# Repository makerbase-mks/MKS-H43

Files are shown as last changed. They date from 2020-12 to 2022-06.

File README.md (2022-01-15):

# MKS-H43
MKS H43 is a 4.3-inch high-definition IPS display with a resolution of 800*480 and uses a capacitive touch screen. It is a high-end screen, which be adapted to most FDM 3D printer motherboards on the market， very suitable for 3D printer upgrades.
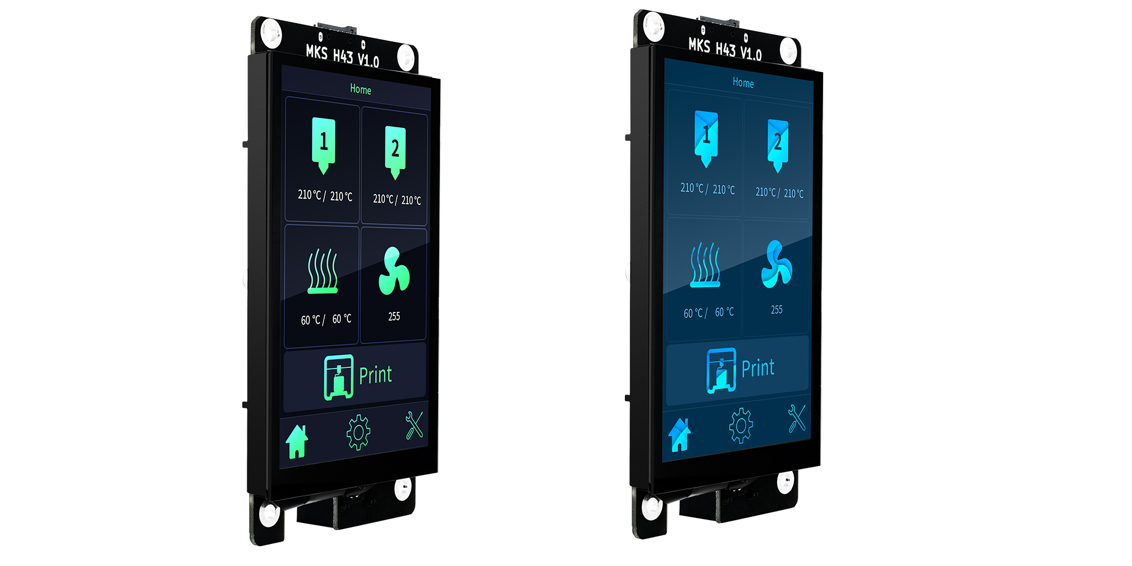
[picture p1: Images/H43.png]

# Feathers
```
—————————————————————————————————————————————————————————————————————————
   Display Size                  4.3 inches
_________________________________________________________________________
   Resolution                    800*480
_________________________________________________________________________
   LCD material                  IPS
_________________________________________________________________________
   Touch screen                  Capacitive touch screen
_________________________________________________________________________
   Interface with motherboard    RJ11/AUX-1(Uart TTL)
_________________________________________________________________________
                                 MKS SGEN_L
                                 MKS Robin Nano Series          
                                 MKS Robin E3/E3D/E3P
                                 Creality3D V1.1.4(Ender3/Ender5 raw board)
    Motherboards support         BTT SKR Series
                                 ...
                                 (Theoretically support all motherboards with
                                 serial communication and running marlin V2.X firmware)
__________________________________________________________________________
   Communicate Protocol          DWIN DGUS
__________________________________________________________________________
```

# Motherboards support
MKS H43 is a serial LCD, it uses the TTL-UART to communicate with motherboards. So in theory, MKS H43 supports all motherboards with serial communication and running marlin V2.X firmware. As there are so many types of 3d printer motherboards, different motherboard has different uart available and unavailabe, so we make some test of the compatibility of MKS H43 and some motherboards, please refer to the [wiki page](https://github.com/makerbase-mks/MKS-H43/wiki).

# How to use
## Hardware connect
As we mentioned above, MKS H43 just uses TTL-UART to connect to the motherboard, in fact the 4 pin signals are:
```
DC5V
GND
UART-TX
UART-RX
```
And we designed two types of uart sockets on MKS H43: one AUX and one RJ11. We also made two type of adapter boards for connecting different motherboards: 
```
MKS H43 Apdator-A: Convert from RJ11/AUX to EXP1/EXP2 interface of most motherboards, it also extends a SD socket
MKS H43 Apdator-B: Convert from RJ11 to AUX-1 interface of most motherboards, and EXP1 of Creality3D V1.1.4 
```
The reason we added RJ11 socket is to allow users to use a spring wire (the microphone cable of an old telephone) to connect to the screen, so that the screen can be easily manipulated and placed.

What have to be aware of is: As the MKS H43 communicates with the motherboard using DWIN DGUS protocol, which is different from the simple gcode commands, so the motherboard should use a serial port different from the PC connection to connect to MKS H43, unless you don’t need PC control. So maybe your motherboard has the "AUX-1" socket, but if it shares the same serial port with the PC connection, you cannot connect at the same time.

There are many situations for different motherboards:
- With independent serial on AUX-1 interface, such as MKS SGEN_L V1/V2, you can use Adaptor-B adapter board
- With independent serial on EXP1/EXP2 interface, such as MKS GEN_L, which can use the Adaptor-A adapter board
- Without independent serial ports on AUX-1 or EXP1/EXP2, but there are independent serial ports with other forms of interfaces. You can use the Adaptor-B adapter board and use the corresponding cable to switch, such as Creality3D V1.1.4 / MKS Robin Nano V1/V2/V3 / BTT SKR V1.3/V1.4
- Only with the shared serial with PC connection, you can only use MKS H43 without PC connection.
- No serial interface(very rare), cannot use MKS H43

And for different motherboards, you can refer to the detail connection and configuration on [WIKI](https://github.com/makerbase-mks/MKS-H43/wiki).

The hardware information of MKS H43 and adaptor boards, you can refer to : https://github.com/makerbase-mks/MKS-H43/tree/main/hardware.

## Motherboard firmware
We have added the support to Marlin V2 firmware and uploaded the source code here: https://github.com/makerbase-mks/Marlin-V2.X-MKS-H43. At the time of writing this article, Marlin officially has not merged the support of MKS H43, after Marlin merge, you can directly use the official one.
### For Creality Ender3
There is a compiled-Marlin version for Creality Ender3 raw board Creality V1.1.4 on https://github.com/makerbase-mks/MKS-H43/tree/main/Marlin_firmware_released. It was compiled from the source code: https://github.com/makerbase-mks/Marlin-V2.X-MKS-H43, and had added the support of MKS H43.
### Marlin Config
1. Download the source frome: https://github.com/makerbase-mks/Marlin-V2.X-MKS-H43.
2. Using VSCode to open Marlin source, and modify the motherboard type on the "platformio.ini" according to yours, just like:
```
default_envs = mks_robin_nano35
```
3. Config the MKS DWIN
- Open the "Configuration.h" file, find "DGUS_LCD_UI_MKS" and enable it,
- Open the "Configuration_adv.h" file, find "LCD_SERIAL_PORT", and configure the serial port number used to connect to H43. Please make sure that "LCD_SERIAL_PORT" should be different with the "SERIAL_PORT" in "Configuration.h", as "SERIAL_PORT" is used to communicate with the PC. And the baudrate should be set to 115200 by default.

After config other options according to your machine, compile the source code, and update your motherboard. Then you can use the MKS H43 to display and touch!

## Update the firmware of MKS H43
The firmware of MKS H43 has been burned before leaving the factory, so it is generally not necessary to update the firmware. But if you need to update the firmware version, or you want to customize the display interface, you can update according to the following method:
1. Prepare a TF card, format the TF card into FAT32 format, with 4096 bytes aligned.
2. The firmware of MKS H43 can be found on https://github.com/makerbase-mks/MKS-H43/tree/main/DWIN_SET_For_H43, download the version you need. Copy "DWIN_SET" folder to TF card after decompression.
3. Power off the MKS H43, insert the TF card into MKS H43, then power on. An automatic update interface will appear on LCD. Waiting for the screen to display the word “end” which indicates that the update is successful. Generally, the update time is within 1 min.

Note:
1. The insertion and removal of the TF card needs to be done when the power is off.
2. During the TF card update process, do not directly unplug the TF card, which will easily cause the firmware to be destroyed.
3. If the LCD doesn't display the blue update interface after the update begin, you should check whether the name of folder is wrong. 

## Customize MKS H43 UI and functions
If you want to customize your own UI on MKS H43, or modify some functions, you can using the "DGUS Tool" to make it, only support Windows OS so far:
1. Download the "DGUS_Tool_Vxxx.rar" from https://github.com/makerbase-mks/MKS-H43/tree/main/Tool, this is the tool use to edit the firmware of H43. Decompress it and run the "DGUS Tool Vxxx.exe". The default language is Simplified Chinese, you can config to English on the menu of "配置"(Setting)->Language.
2. Download the source code of MKS H43 from https://github.com/makerbase-mks/MKS-H43-firmware, open the project file "DWprj.hmi" file with the DGUS Tool above.
3. Now you can change the size of images/replace your own images or modify the execute functions and so on. More details about how the operate steps, please download the [T5L_DGUSII Application Development Guide](https://github.com/makerbase-mks/MKS-H43/blob/main/Tool/T5L_DGUSII%20Application%20Development%20Guide20200902.pdf).
4. After your modification, select the "DWIN ICL Generator" on DGUS TOOL's welcome page, it will generate the files for burned.
5. Copy the "DWIN SET" folder to the TF card(make sure it has been formated as FAT32 format with 4096 bytes aligned before, and insert it into MKS H43 board, reboot the board and it would update automatically.

Note: More detail about customizing the UI and functions, please download the [T5L_DGUSII Application Development Guide](https://github.com/makerbase-mks/MKS-H43/blob/main/Tool/T5L_DGUSII%20Application%20Development%20Guide20200902.pdf).

## Shell and mounting bracket model
Stl files for Shell and mounting bracket modles of MKS H43 can be downloaded from: https://www.thingiverse.com/thing:4720988

## Note
- Thank you for using MKS products. If you have any questions during use, please contact us in time and we will work with you to solve it.
- For more product dynamic information and tutorial materials, you can always follow MKS's Facebook/Twitter/Discord/Reddit/Youtube and Github. Thank you!
- MKS Github: https://github.com/makerbase-mks  
- MKS Facebook: https://www.facebook.com/Makerbase.mks/  
- MKS Twitter: https://twitter.com/home?lang=en  
- MKS Discord: https://discord.gg/4uar57NEyU
- MKS Reddit: https://www.reddit.com/user/MAKERBASE-TEAM/ 

mks_link

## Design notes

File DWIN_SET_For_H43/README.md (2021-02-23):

# Update logs

## Data:2021/02/09       Version: V1.31

### Content:

1. Change to be green-theme-UI, the display effect is more HD
2. Add LCD backlight control
3. The marlin version on mainboard needs to be [updated](https://github.com/makerbase-mks/Marlin-V2.X-MKS-H43) to be the lastest one synchronously
4. Now there are two theme of UI, you should use as follow:
 
| UI THEME | H43 firmware version | Mainboard Marlin configuration |
| --- | --- | --- |
| green-theme-UI | V1.30 | In "DGUSDisplayDef.h" //#define USE_MKS_GREEN_UI |
| blue-theme-UI  | V1.31 | In "DGUSDisplayDef.h" #define USE_MKS_GREEN_UI |

## Data:2021/01/15       Version: V1.30

### Content:

1. The basic version, with the blue-theme-UI.

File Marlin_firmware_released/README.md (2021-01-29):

# Introduce
Marlin_H43_for_Creality_ender3.hex is an compiled firmware of Marlin firmware for Creality Ender3 raw board Creality V1.1.4. It was compiled from the source code: https://github.com/makerbase-mks/Marlin-V2.X-MKS-H43, and had added the support of MKS H43. 

# How to upload
If your Creality V1.1.4 has bootloader, you can use [xloader](http://www.hobbytronics.co.uk/download/XLoader.zip) to upload the .hex firmware.

If your Creality V1.1.4 doesn't has bootloader, you should use the [USB ISP module](https://www.aliexpress.com/item/4001211961989.html?spm=2114.12010615.8148356.12.6b2d2c13ei8zzR) to upload. 

Hint:Why does some boards have no bootloader? Because the flash of the main control chip mega1284p is too small, if the marlin firmware you use is too large, the bootloader may be flushed after the upgrade.

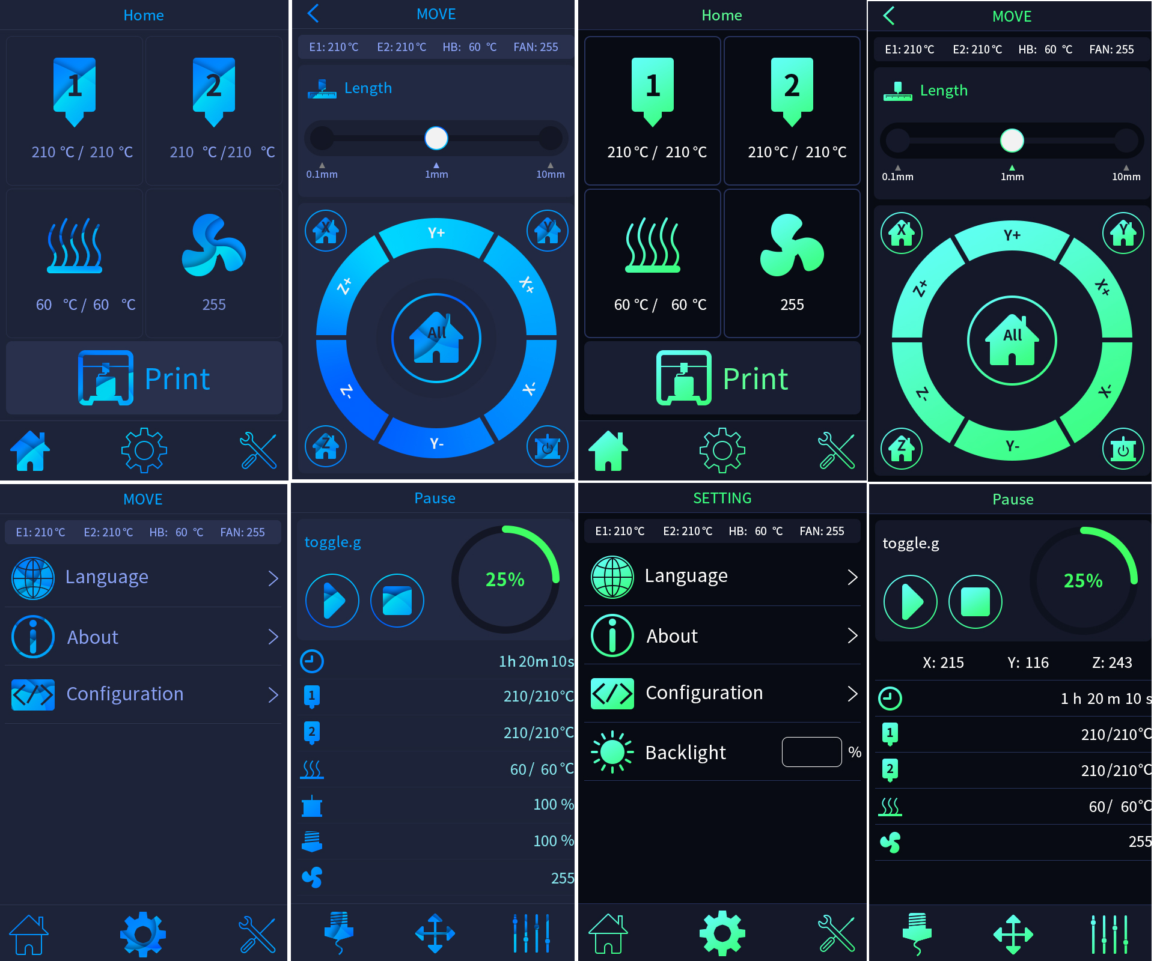
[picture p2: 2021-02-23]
Images/BLUE_GREEN.png

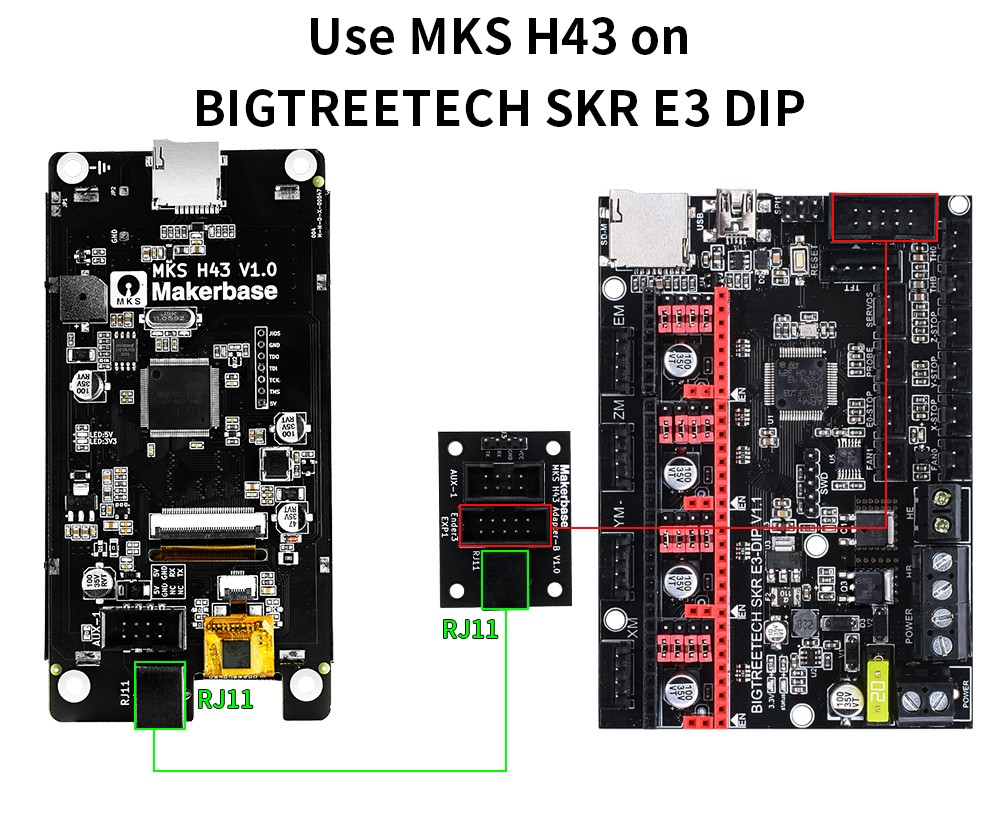
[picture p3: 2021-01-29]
Images/H43_SKR_E3_DIP.jpg

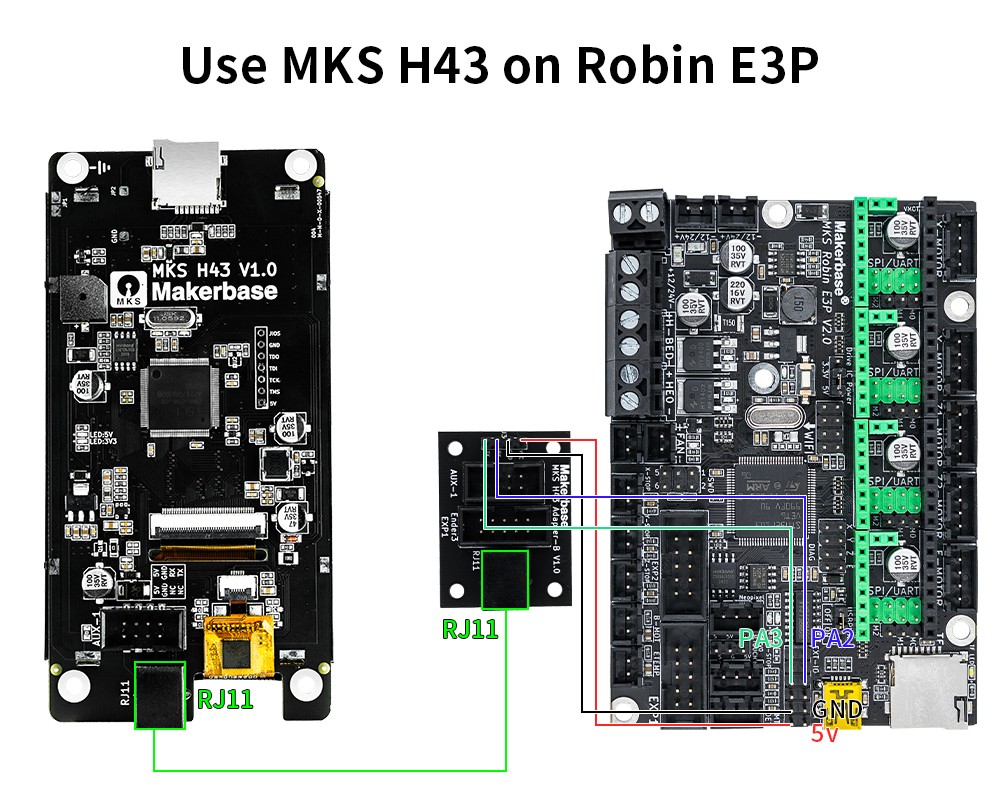
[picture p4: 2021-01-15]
Images/H43_ROBIN_E3P.jpg

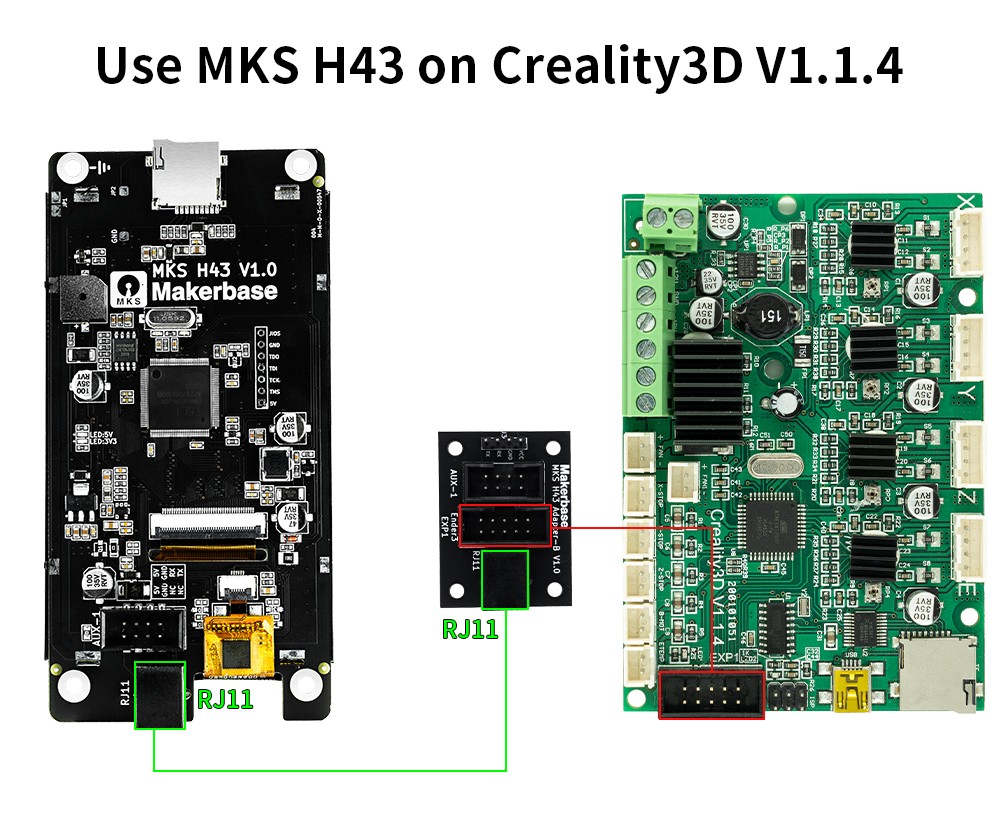
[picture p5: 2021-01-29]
Images/H43_CREALITY3D_114.jpg

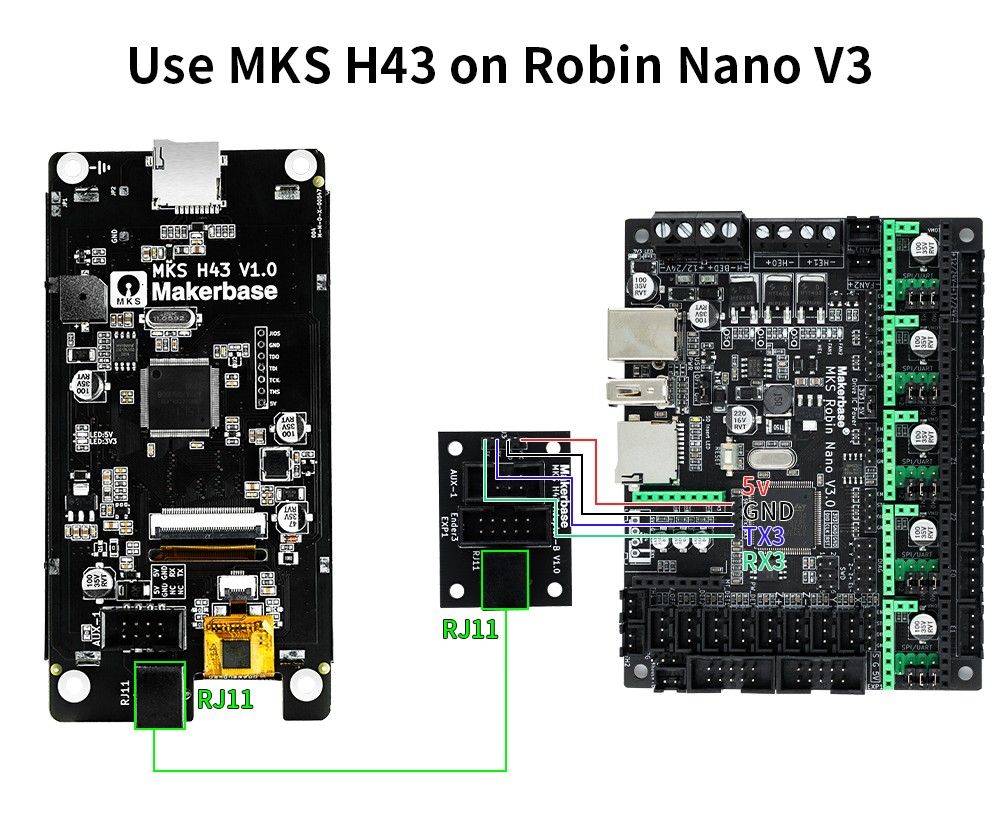
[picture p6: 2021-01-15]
Images/H43_ROBIN_NANO_V3.jpg

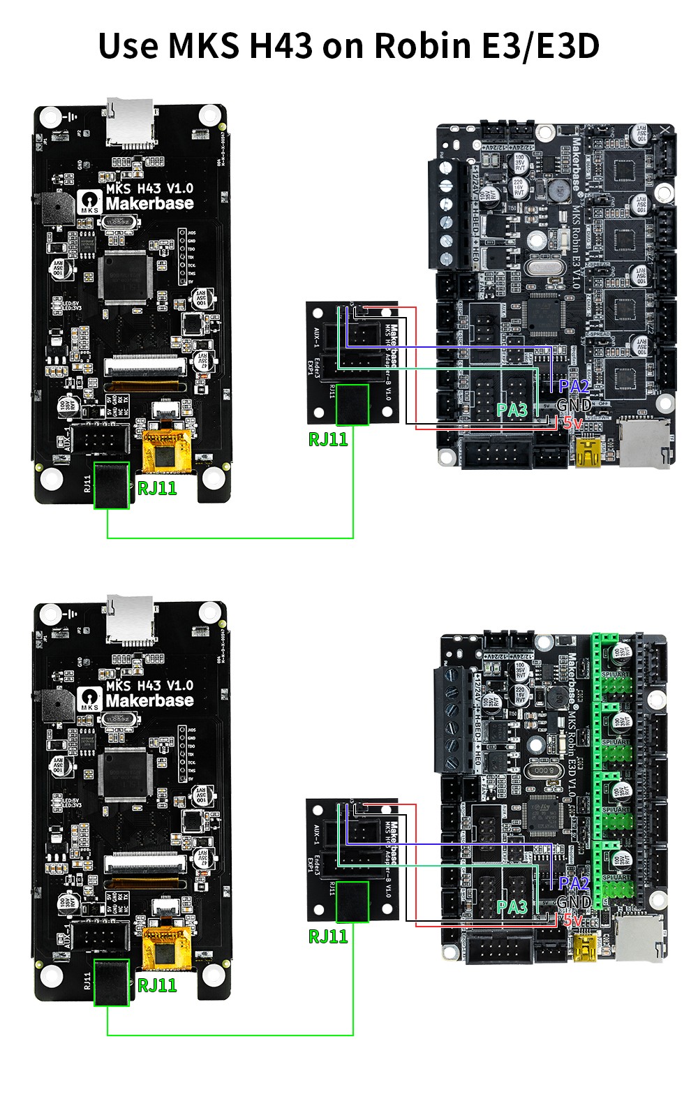
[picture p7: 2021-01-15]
Images/H43_ROBIN_E3_E3D.jpg

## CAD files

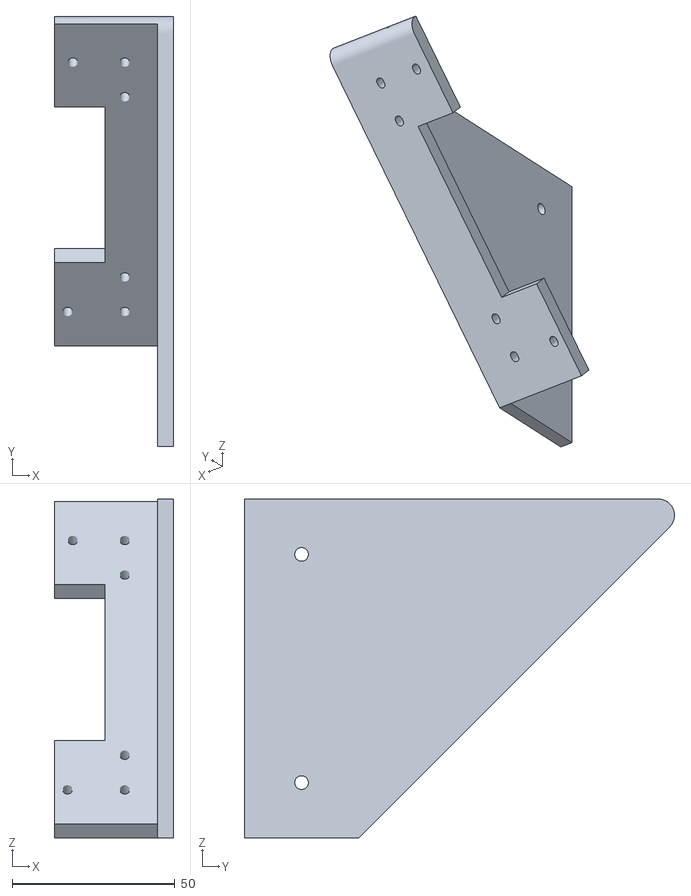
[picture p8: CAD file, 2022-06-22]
modules/bracket1.STL
36.6 x 131.9 x 104.0

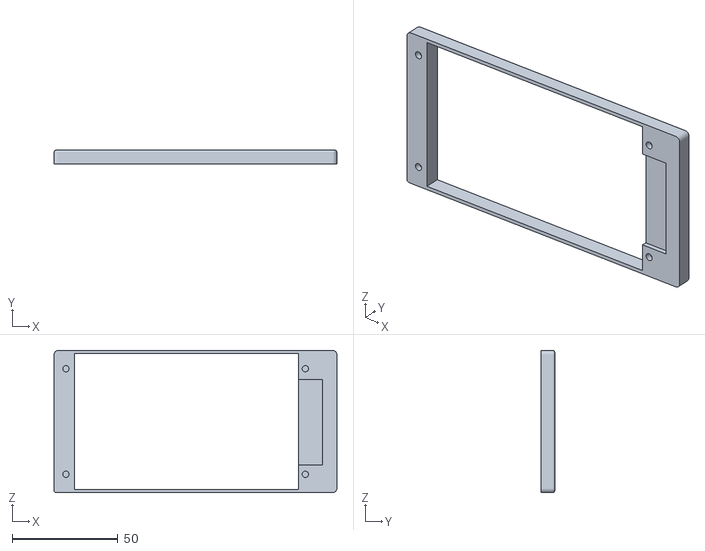
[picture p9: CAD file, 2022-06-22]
modules/shell1.STL
134.1 x 6.50 x 67.3

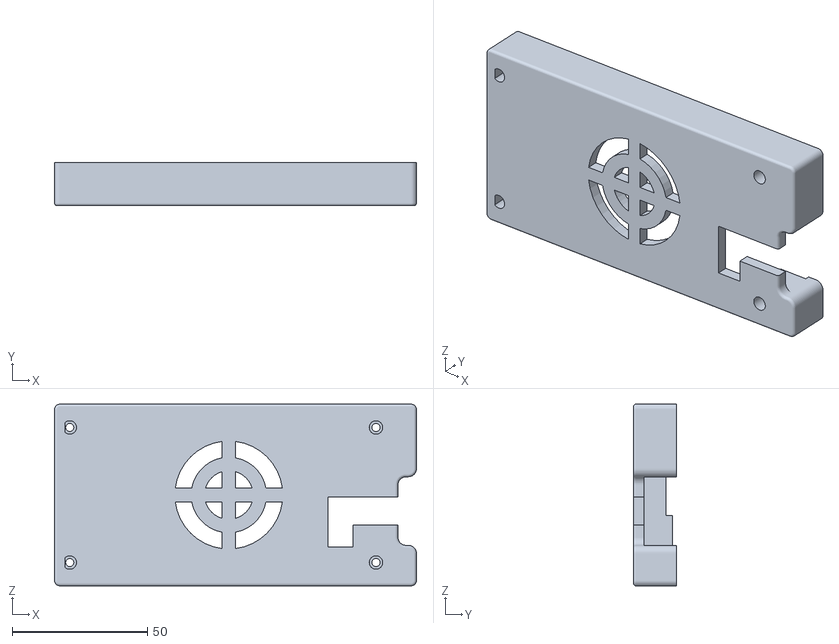
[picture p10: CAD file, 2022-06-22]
modules/shell2.STL
134.1 x 16.1 x 67.3

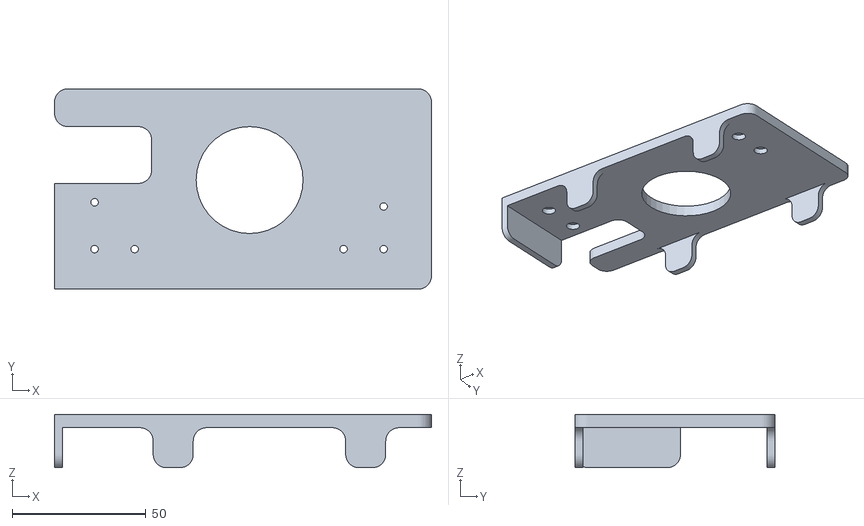
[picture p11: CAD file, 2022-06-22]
modules/bracket2.STL
141.1 x 75.0 x 20.0

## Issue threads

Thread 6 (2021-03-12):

H43 screen says it is printing every time I turn it on.

Voxel3DPrinting, 2021-03-12:
Hey,
I configued marlin to my printer and am ready to use it. When I upload the firmware everything works, exept I cannot change the language to English. I am able to move inside the menu's however..
How can I fix this?
Also, when I boot the printer, it starts up wit a screen that indicates it is printing.
I hope to hear from you.

Voxel3DPrinting, 2021-03-12:
I have tested a second H43 screen (bought 2 for my 2 printers) and I have gotten that one to work in english now. However, it still thinks it is busy printing when I boot the printer. Also, the UI theme is Blue whilst I uncommented the line "#define USE_MKS_GREEN_UI " ...

Voxel3DPrinting, 2021-03-14:
Also fixed, it turned out I had to update the H43's firmware to 1.31.

Closed 2021-03-14.

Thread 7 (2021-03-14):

H43 does not read SD card at all, and cannot boot with SD card inserted

Voxel3DPrinting, 2021-03-14:
Hey,
My H43 screen does not read the SD cards for my GCODE files, I am using an MKS SGen L V2, with MKS2209 drivers and configured marlin exactly as the Wiki said..
I also have tried multiple SD cards of different sizes (4-32GB), and formatted them in different ways / cluster sizes.
Note:
If I insert the SD card while the printer is on, it just does not read anything. If I insert the SD card before booting, and the printer boots, the screen just gets slightly dim and does not boot any further.

Edit;
I think I at least got something figured out;
In the marlin V2.0 you provided for the H43, it defaults to "#define SDCARD_CONNECTION LCD" in Configuration.adv. However, If i check the "Pins" file of my main board (MKS Sgen L V2) it says;
"#if SD_CONNECTION_IS(LCD) || SD_CONNECTION_IS(ONBOARD)
  #define SD_DETECT_PIN                    P0_27
  #define SD_SCK_PIN                       P0_07
  #define SD_MISO_PIN                      P0_08
  #define SD_MOSI_PIN                      P0_09"

However, those pins (P0_27, P0,07, P0_08 and P0_09) are located in the EXP-1 connector instead of the AUX connector. (See pinout of MKS SgenL V2; https://github.com/makerbase-mks/MKS-SGEN_L-V2/wiki/Hardware_description#Wiring_Pinout_and_Size)

I think it has to do something with this and somehow need t change those pins from the EXP-1 connector to the AUX connector which the H43 is connected to. But I cannot figure out how I can do this, does anyone have any ideas?

Jontux, 2021-04-06:
Same here with an H43 connected to a SKR V1.4 Turbo. SD card does not appear neither with the SD card connected to an H43 nor mainboard.

reQu1em00, 2021-04-07:
I can now get it working but only with a very small SD card.  128MB worked for me.  No other size will work even though I can update firmware with a larger version.

Voxel3DPrinting, 2021-04-07:
I modified the Board file and I now can read the Gcode from the onboard SD, but the screen SD does nothing. Contacted MKS via Ali and they said the H43 cannot read Gcode..
Maybe an Idea to put this information somewheere @mks-viva @makerbase-mks ??

Jontux, 2021-04-07:
I noticed also that Marlin tryes to read the SD card from pins of AUX-2 when the screen is set to MKS H43. Mainboard is SKR 1.4 Turbo.

But ok, I bought the H43 to read the SD card and to control printer but nice to know if it doesn't even read the G-code 😅 I would like to know if it's even possible to do so with some firmware changes 🤔

Voxel3DPrinting, 2021-04-08:
> I noticed also that Marlin tryes to read the SD card from pins of AUX-2 when the screen is set to MKS H43. Mainboard is SKR 1.4 Turbo.
>
> But ok, I bought the H43 to read the SD card and to control printer but nice to know if it doesn't even read the G-code 😅 I would like to know if it's even possible to do so with some firmware changes 🤔

Same exact problem here.. I just grinded a slot in my printers case to get acces to the SD slot. I fixed the reading issue by changing the Board pins file and settin gthe SD mode to "ONBOAD"
Maybe this works 4 u to

Metalazzo, 2021-04-24:
I have the same problem. I cannot boot with a micro sdcard inserted in the H43 LCD (black screen, I suppose it tries to update) or if I plug it after boot, there is no file found. Read perfectly gcode files from E3D main board.
I think it's really stupid coming from MKS. And I don't understand why "it cannot read gcode". Well according to schematic it can. That they don't want to make any effort on the software side, it's an other story.
Finally, I found their lack of support disturbing... For example, you can't have a BLtouch and neopixel plugged on a MKS E3D and H43 out of the box, you need to reassign pins.

buiduy6868, 2021-06-05:
@Voxel3DPrinting
Hi bro, have you solve your problem, I got the same issue with my H43+MKS Sgen L V2. I dont know how to do now

Voxel3DPrinting, 2021-07-09:
It appears the SD on the screen is only ment for updating the H43 screen and not for data transfer.
For the Gcode files you have to use the motherboard SD

Closed 2021-07-09.

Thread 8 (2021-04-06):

Move buttons don't do anything

Jontux, 2021-04-06:
When I home the printer it works well but when I try to move any plane with x+, x-, y+, y-, z+ or z- button, it doesn't do anything.

I'm using MKS H43 v1.0 with v3.1 firmware.
Mainboard is SKR V1.4 Turbo with TMC2209.
Marlin firmware is 2.0-MKS-H43.

I don't know if this is because of Marlin firmware config or a bug in MKS H43 firmware.

Voxel3DPrinting, 2021-04-07:
Homing works you say? and what if you try connecting it to a PC with pronterface?

Jontux, 2021-04-07:
Yes homing works well and with pronterface I can move all axels, but moving with a H43 doesn't work.

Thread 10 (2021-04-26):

not able to update to last firmware

spilz87, 2021-04-26:
hello everyone

i'm trying to update last firmware of the H43 download here : [H43_Firmware_for_Malin](https://github.com/makerbase-mks/MKS-H43/tree/main/DWIN_SET_For_H43/H43_Firmware_for_Malin)

What I did :

I formated my micro SD card in FAT 32, with 4096 bytes aligned.
I created a folder named "DWIN_SET" and paste all files downloaded.
I disconnected the H43 display
I inserted the SD card
I connected the H43 display to power.
A blue screen appared
i saw files which are downloaded and after around 1 minute, the "end" is displayed
I disconnected the display
I remove the sd card
I turn off the printer
I reconnect the display
I trun ON the printer

In "About" menu I still have "MKS H43_V1.30" instead of "MKS H43_V1.31"
and I still have the issue with temperature values like if I didn't update it.

did someone was able to update it correctly ?
what did I do wrong ?

thanks for your help

Spliz

spilz87, 2021-04-30:
Up ... ?

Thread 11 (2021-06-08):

MKS H43+Robin Mano 3 stops at the logo

YuraBz, 2021-06-08:
Hi, the screen from the box not booting, I tried to refill all the firmware, configured according to the instructions, nothing helped.  After loading it stops at the mks logo.
Connected to mks robin nano 3

Soprano80, 2021-06-13:
https://github.com/makerbase-mks/MKS-H43/wiki/Use-MKS-H43-on-different-motherboards#mks-robin-nano-v3

Marlin-Konfiguration:

Configuration.h:

#define SERIAL_PORT -1
#define BAUDRATE 115200

Configuration_adv.h:

#if HAS_DGUS_LCD
#define LCD_SERIAL_PORT 3
#define DGUS_BAUDRATE 115200

YuraBz, 2023-03-18:
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
sorry but its not work. i try couple version and firmware

Crackerdent, 2023-12-19:
> 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 sorry but its not work. i try couple version and firmware

Hi YuraBz,
I have same issue.  I bought a new mks h43 display for a corexy printer and it gets stuck on the green logo. I tried to upload a few times new firmware. But it's not work. I am using with Mks Robin nano v3, same board.
How did you do it? Can you help me?

YuraBz, 2023-12-20:
Hi. Yes. I have working firmware. Try to find tomorrow and let you know

easybusy.com.ua
***@***.***
0660501282

вт, 19 груд. 2023 р. о 15:26 Crackerdent ***@***.***> пише:

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

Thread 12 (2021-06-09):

Can't set english language

matthgyver, 2021-06-09:
Hi,

In the language selection menu, I show chinese and english but if I click on english item, nothing is happening. I hear bip sound but the select indicator keep on chinese item.

I'm using [your firmware](https://github.com/makerbase-mks/Marlin-V2.X-MKS-H43).

I've tried  with both of your LCD : firmware H43_Firmware_1.31 and H43_Firmware_for_Malin and the result is the same.

Could you help me please ?

Thank's

matthgyver, 2021-06-10:
It's was a serial connection problem.

mlueft, 2021-06-20:
what‘s your solution? I habe the same problem.

regards,

michael

matthgyver, 2021-06-20:
It's was a serial connection problem. If the screen can't communicate with the board, you can't modify some parameters
On my Rumba32 board, I've connected my screen on A9 & A10 pins and set ``#define SERIAL_PORT -1`` into my configuration.h

Closed 2021-06-10.

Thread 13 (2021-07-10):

Baby Stepping Supported ?

Aayushg416, 2021-07-10:
WHile compiling marlin 2.0.9.1

it says like this

Compiling .pio\build\mks_robin_e3\src\src\lcd\extui\dgus\mks\DGUSScreenHandler.cpp.o
Marlin\src\lcd\extui\dgus\mks\DGUSScreenHandler.cpp: In static member function 'static void DGUSScreenHandler::HandleLiveAdjustZ(DGUS_VP_Variable&, void*)':
Marlin\src\lcd\extui\dgus\mks\DGUSScreenHandler.cpp:1129:10: warning: unused variable 'babystep_buf' [-Wunused-variable]
 1129 |     char babystep_buf[30];
      |          ^~~~~~~~~~~~

      Looks like its been missing in the file

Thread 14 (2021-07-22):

MKS H43 Extrude Filament Buttons Backwards

CollinCBoring, 2021-07-22:
In the Extrude Menu, the In and Out buttons are reversed. The left button with the arrow aiming down should extrude, and the other should retract.
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

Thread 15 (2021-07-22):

MKS H43 Temp Sensors Not Reading Properly

CollinCBoring, 2021-07-22:
I am using the Robin Nano V3 with the latest Marklin 2.0 from the Makerbase Github.  When I use the TFT35 V2. the temperatures read properly, but when I program for the H43, the temps swing between -9000 and 9000 rapidly.  The machine will still preheat and print even though the H43 is displaying the data wrong.  The Nano V3 seems to know the temps but the H43 is displaying them wrong.
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

CollinCBoring, 2021-07-30:
Any Progress on this issue @makerbase-mks ?

CollinCBoring, 2021-08-30:
@MKS-Sean @makerbase-mks Any Progress Here???

slapukas, 2021-09-01:
Robin Nano V3 and MKS H43 wrong  temetarure:(((

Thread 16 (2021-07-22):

MKS H43 BabySteps has no Back Button

CollinCBoring, 2021-07-22:
While a part is 3D printing, go to settings > Babystepping.  There is no back button to return to the previous menu or printing status screen.  When you click the number for babysteps, it will return you to the previous page but there should be a button like the rest of the menus.

CollinCBoring, 2021-07-30:
Any Progress on this issue @makerbase-mks ?

omrfrkmll, 2023-04-24:
https://www.mediafire.com/file/pog0uwfol2yvpja/DWIN_SET.rar/file
download and flash to your screen. it shoul work. I add a return button to babystep screen.

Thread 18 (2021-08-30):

Unable to change language on display

josurr, 2021-08-30:
Using the H43 (v1.0) on an Ender-3 v2 with the latest Marlin 2.0.x bugfix.

I have enabled the LCD correctly (although I have only been able to get to the main menu when the LCD serial port is set to 3 and not 1 or 2).

I also noticed that the back arrow on the Print screen (with the list of the various files on the SD card) does not work.

Additionally, the +/- axis buttons are non-functional on the Move screen.

I have flashed my H43 with the non-beep version of v1.31 (from [https://github.com/makerbase-mks/MKS-H43/tree/main/DWIN_SET_For_H43/H43_Firmware_for_Malin](https://github.com/makerbase-mks/MKS-H43/tree/main/DWIN_SET_For_H43/H43_Firmware_for_Malin))

There also does not seem to be a way to switch to the blue UI, as commenting out the GREEN_UI line causes the printer to think that it is printing on boot (display shows a "Stop Print" message), and if yes/no is chosen (or no action is taken for about 5 seconds) the screen changes to the second frame of the boot "animation" and freezes.

I was hoping that this LCD screen would be an upgrade for my printer and allow me to visualize the mesh leveling graph of the print bed, but at this point, I am seriously contemplating returning the screen to Amazon.

jorgejglopez, 2023-01-20:
I too have had the same problems.  I have tried all the firmwares and the only ones that have worked well for me are those of version 1.30.

omrfrkmll, 2023-04-24:
Hello;
for "I also noticed that the back arrow on the Print screen (with the list of the various files on the SD card) does not work."
>you should edit the screen firmware with given on MKS H43 firmware ->https://www.dwin-global.com/tool/ -> T5L menu -> DGUS_V7641[DOWNLOAD](https://www.dwin-global.com/uploads/DGUS_V7641-0801.zip)
also you need download the source DWIN_SET file from -> https://github.com/makerbase-mks/MKS-H43-firmware (choose compatible one)
open DWprj.hmi
go to page that you need edit.
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

on left side you can see the "page switching" section
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
click the set button and select home page.
than upper left side under "common" menu you can see that icons
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

click them and save three of them.
all done. you just copy the DWIN_SET file to your SD card and flash to the MKS H43

-I just mentioned. not explained detailly. if you need help please write me...
I hope it is helpful :)

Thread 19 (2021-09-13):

Cannot Hit Back Button in "Print" Menu

CollinCBoring, 2021-09-13:
I downloaded the DWIN_SET 1.31 and uploaded to my H43. When you click the "Print" button on the main screen, the return arrow in the top left does not work.
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

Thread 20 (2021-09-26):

H43 on Robin Nano S 1.3

Bergateo, 2021-09-26:
Hi everyone, I would like to know if is it possible to connect the display on the board mentioned on the title and how eventually.
Because I canot find the RX1 and TX1 pin on the scheme of the board nor the aux...

Cyberyoryo, 2021-12-15:
I have managed to get it to work with a SKR mini E3 V3.0 but the language cannot be changed.  After many tests in configuration_adv.h I put serial_port 1 in DGUS and serial _port 2 in configuration.h

LiamTal, 2022-06-24:
> I have managed to get it to work with a SKR mini E3 V3.0 but the language cannot be changed. After many tests in configuration_adv.h I put serial_port 1 in DGUS and serial _port 2 in configuration.h

Hi, maybe you could explain how you solved it in #24378 https://github.com/MarlinFirmware/Marlin/pull/24378

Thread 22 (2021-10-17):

Where does "Auto Turn Offff" string come from ?

ImTheBadWolf, 2021-10-17:
On print settings page, the last item in the menu is auto turn off. But the text displayed is "Auto Turn Offfff".
Where does this text come from ? The text display component has set  VP address to 0x5690, but i cant seem to find this address in the Marlin string definitions.

The same goes for "YES" and "NO" buttons on error and warning prompts. I want to change the text of those buttons but i cant find the string definition ?
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

Closed 2021-10-17.

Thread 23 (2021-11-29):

#define LASER_FEATURE crash H43 in english

filipdns, 2021-11-29:
Using MKS Gen L V2.1 with latest Marlin bug fix and H43 under firmware 1.30:
all is working in Chinese language but when I switch in English, all is making any thing, servo x and y move and overshoot min switch and after few second the H43 go back to Chinese himself and the printer is locked and have to be reset..

Steps to Reproduce

only uncomment #define LASER_FEATURE in Configuration_adv.h
Additional Information

to be able to use laser with hot bed I had to add #define HEATER_BED_PIN MOSFET_A_PIN in pin_RAMPS
[Marlin.zip](https://github.com/makerbase-mks/MKS-H43/files/7616722/Marlin.zip)
.h

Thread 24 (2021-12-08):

Can't update the H43 Firmware

neTix84, 2021-12-08:
Hello,

i downloaded the firmware  from https://github.com/makerbase-mks/MKS-H43/tree/main/DWIN_SET_For_H43/H43_Firmware_for_Malin

I followed the instructions:
- Copy "DWIN_SET" folder to TF card after decompression.
- Power off the MKS H43, insert the TF card into MKS H43, then power on. An automatic update interface will appear on LCD.

When i use the Firmware for Marlin:
The update interface appears, but while loading the files ...
CFG...1...fine
Code...0...fine
BIN...it stops

When i use the normal Version:
CFG...1...fine
Code...0...fine
BIN...4...fine
S2K...it stops

Any idea?

ngoalongcang, 2022-04-02:
some one have anser?

sherwinrastegar, 2023-09-12:
Hello,
how was your problem solved? I have this problem
how can i upload frimware ?

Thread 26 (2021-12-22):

impossible change the language

Cyberyoryo, 2021-12-22:
There is no way to make the screen work and less to change the language. I have tried with the latest marlin that brings support for the screen and it does not work with any of the three updates that you have in the repository. I have tried with the marlin that you provide, I even bought a plate that was compatible with that version of marlin, and there is no way to make it work or change the language.
The truth is that I spent € 50 on the screen and € 45 on a MKS motherboard compatible with the screen and with the marln that you provide and there is no way to make it work.
No more buying MKS products, recommending MKS and everything that has to do with MKS.

AlexStepnogorsk, 2021-12-26:
Редактируй картинки в прошивке экрана.

Cyberyoryo, 2021-12-26:
- [ ] ¿Que más quieres que edite? Le he dado 20 vueltas al firmware.

Cyberyoryo, 2021-12-31:
>

¿Que parte del firmware tendria que editar?
What part of the firmware would I have to edit?
Какую часть прошивки мне придется редактировать?

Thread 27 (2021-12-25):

skr e3 dip

AlexStepnogorsk, 2021-12-25:
Не запускается на skr e3 dip. После запуска только логотип MKS. Как решить проблему?

AlexStepnogorsk, 2021-12-25:
Skr e3 dip v1.1. Порты -1 последовательный и 1 на dgus. И плюсом была проблема с включенной второй осью z. Закрыл ее и проблема пропала

AlexStepnogorsk, 2021-12-25:
Skr e3 dip v1.1. Порты -1 последовательный и 1 на dgus. И плюсом была проблема с включенной второй осью z. Закрыл ее и проблема пропала.

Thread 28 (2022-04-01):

Mks Robin Nano v3.1+tmc2209 uart mode+sensorless config+mks H43 screen

espjom, 2022-04-01:
Hi, How can I configure the voltage for use the tmc motor drivers with the sensorless config and the Mks h43 screen together?. For the sensorless I need to use the 3,3v config and for use the hs43 its 5v. It's possible to use together using 3,3v?
Thanks!

Closed 2022-04-02.

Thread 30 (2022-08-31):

MKS H43 v1.1 on Skr 1.4 turbo

andyrok, 2022-08-31:
I don’t understand to connect the MKS H43 with the  Skr 1.4 Turbo…
Can anyone help me?
Thanks

mlee12382, 2022-08-31:
On my skr mini I just used the 10pin cable to exp1 and adapter B for the H43. Then I assigned the LCD Serial Port in configuration_adv.h to 2 I think it was, I can check when I get home.

andyrok, 2022-09-03:
I can’t connect the H 43 to the SKR 1.4 Turbo. The suggested connection is between the AUX-1 port of the Tft card and the WiFi port of the Skr... I don't have a cable that can get into the Skr socket... I tried to connect them with single cables but the screen at most lights up with the Makerbase logo and stops...🤬

andyrok, 2022-09-09:
After a million tests nothing happens.. the screen remains on the initial logo... do you have any solution?
 the board is SKR 1.4Turbo whit TMC2029

mlee12382, 2022-09-15:
Did you define an lcd serial port in configuration_adv.h under the dgus section? Ie. #if HAS_DGUS_LCD
  #define LCD_SERIAL_PORT 6
  #define LCD_BAUDRATE 115200

andyrok, 2022-09-15:
> Did you define an lcd serial port in configuration_adv.h under the dgus section? Ie. #if HAS_DGUS_LCD
> #define LCD_SERIAL_PORT 6
> #define LCD_BAUDRATE 115200

Are you sure about 6..?
I try 👍

mlee12382, 2022-09-15:
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

I don't think it matters but that's what it is on mine. I think it just needs to be different than something you're using elsewhere.

mlee12382, 2022-09-15:
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

andyrok, 2022-09-15:
I’ve try this option( LCD_SERIAL…) but not other number then 0…. I try tomorrow..👍

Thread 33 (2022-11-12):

MKS-H43 not working MKS-Tinybee

deadstarcan, 2022-11-12:
I didnt manage to use MKS-H43 at Tinybee, what are codes/port number of that?

sherwinrastegar, 2023-09-11:
hello
, how was your problem solved? I have the same problem, and when I compile, it says that the board does not support this display.

deadstarcan, 2023-09-11:
Didnt test it yet, I will look up at weekend

sherwinrastegar, 2023-09-11:
Thank you very much, my friend
 can we communicate more?

deadstarcan, 2023-09-11:
You can email me anytime, canabanoz@gmail.com

sherwinrastegar, 2023-09-11:
thanks my friend
my email is : shervin85rastegar@gmail.com

deadstarcan, 2023-09-11:
You are welcome :)

sherwinrastegar, 2023-09-11:
You have finished making your own printer؟

deadstarcan, 2023-09-11:
Actually I bought an anet a8 clone with fried motherboard and psu, and decided to rebuild all electric and electronic parts. Last week I have printed new hotend adapter for bmg direct drive and didnt power on yet.

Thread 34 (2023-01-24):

Wifi with H43 and robin Nano V3.0

jorgejglopez, 2023-01-24:
Hello, I am trying to activate wifi in marlin for H43 display but it always gives me an error when compiling. I have the screen configured with serial port 3. Has anyone managed to make the H43 screen and Wifi work on the same motherboard?

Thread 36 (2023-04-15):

Language turns simpleChinese every boot

omrfrkmll, 2023-04-15:
Hello;
I tried many things but my screen is turning chinese every boot. English words "home, print" seems 2 seconds and then turns to chinese again.
I will develop a new printer for my company. So I choosed this screen but it looks like useless for this reasons.

any help please!

My set up: BTT SKR MINI E3 V3.0 & MAKERBASE MKS H43

omrfrkmll, 2023-04-16:
Here is the solution:
-Open Marlin folder in Visual Studio Code.
-Go for DGUSDisplayDef.cpp file
-Find mks_language_index definition
-Change "MKS_SimpleChinese" with "MKS_English"

That's all

Closed 2023-04-16.

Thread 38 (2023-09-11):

my board is mks_tiny_bee but say board cant support h43

sherwinrastegar, 2023-09-11:
Hello, how was your problem solved? I have the same problem, and when I compile, it says that the board does not support this display.

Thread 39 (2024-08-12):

Using mks H43 with mks gen L

mahdiabedi75, 2024-08-12:
So I'm not really advanced with this stuff, but had to deal with every possible problem that could happen for making it work (probably)
after fixing it, I would like to share the little I figured.
So the original marlin firmware that was using with TFT 28 vol 4 wouldn't work when defining DGUS LCD. The port was already in use.
So used the Recommended on this site for h43.
And boy, that was a mistake (almost). It went so wrong, didn't know where to start.
After some attempt to fix it.
 Looked for error on the last firmware and find
that it didn't have LCD serial port setting on advanced config like the new one.
So after copied the line changing it according to board and enabling the DGUS LCD mks.
 Everything worked fine. Hope it helps someone.

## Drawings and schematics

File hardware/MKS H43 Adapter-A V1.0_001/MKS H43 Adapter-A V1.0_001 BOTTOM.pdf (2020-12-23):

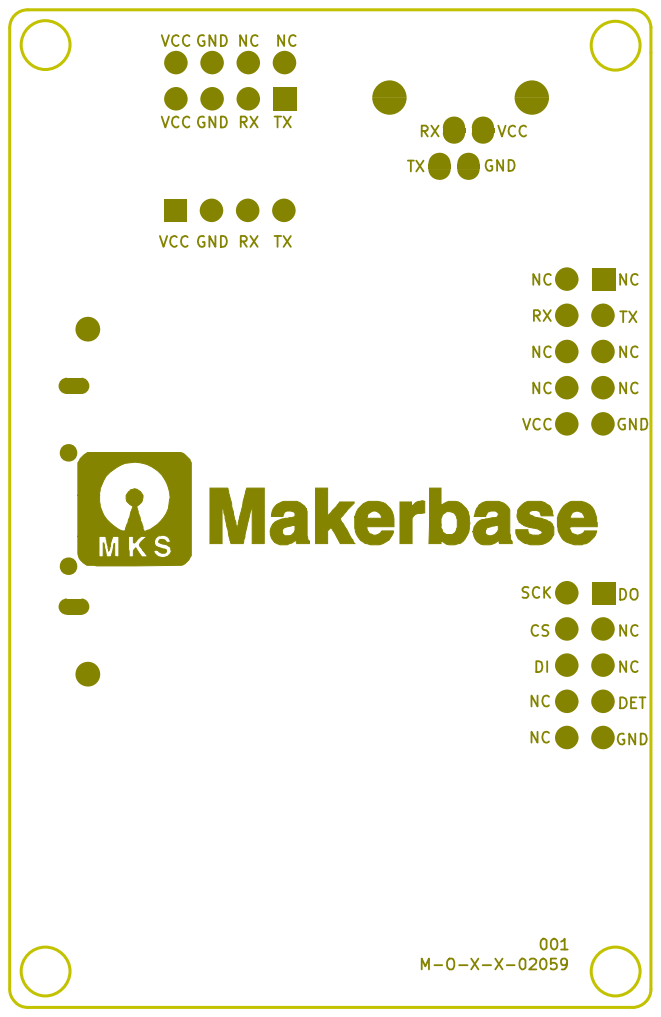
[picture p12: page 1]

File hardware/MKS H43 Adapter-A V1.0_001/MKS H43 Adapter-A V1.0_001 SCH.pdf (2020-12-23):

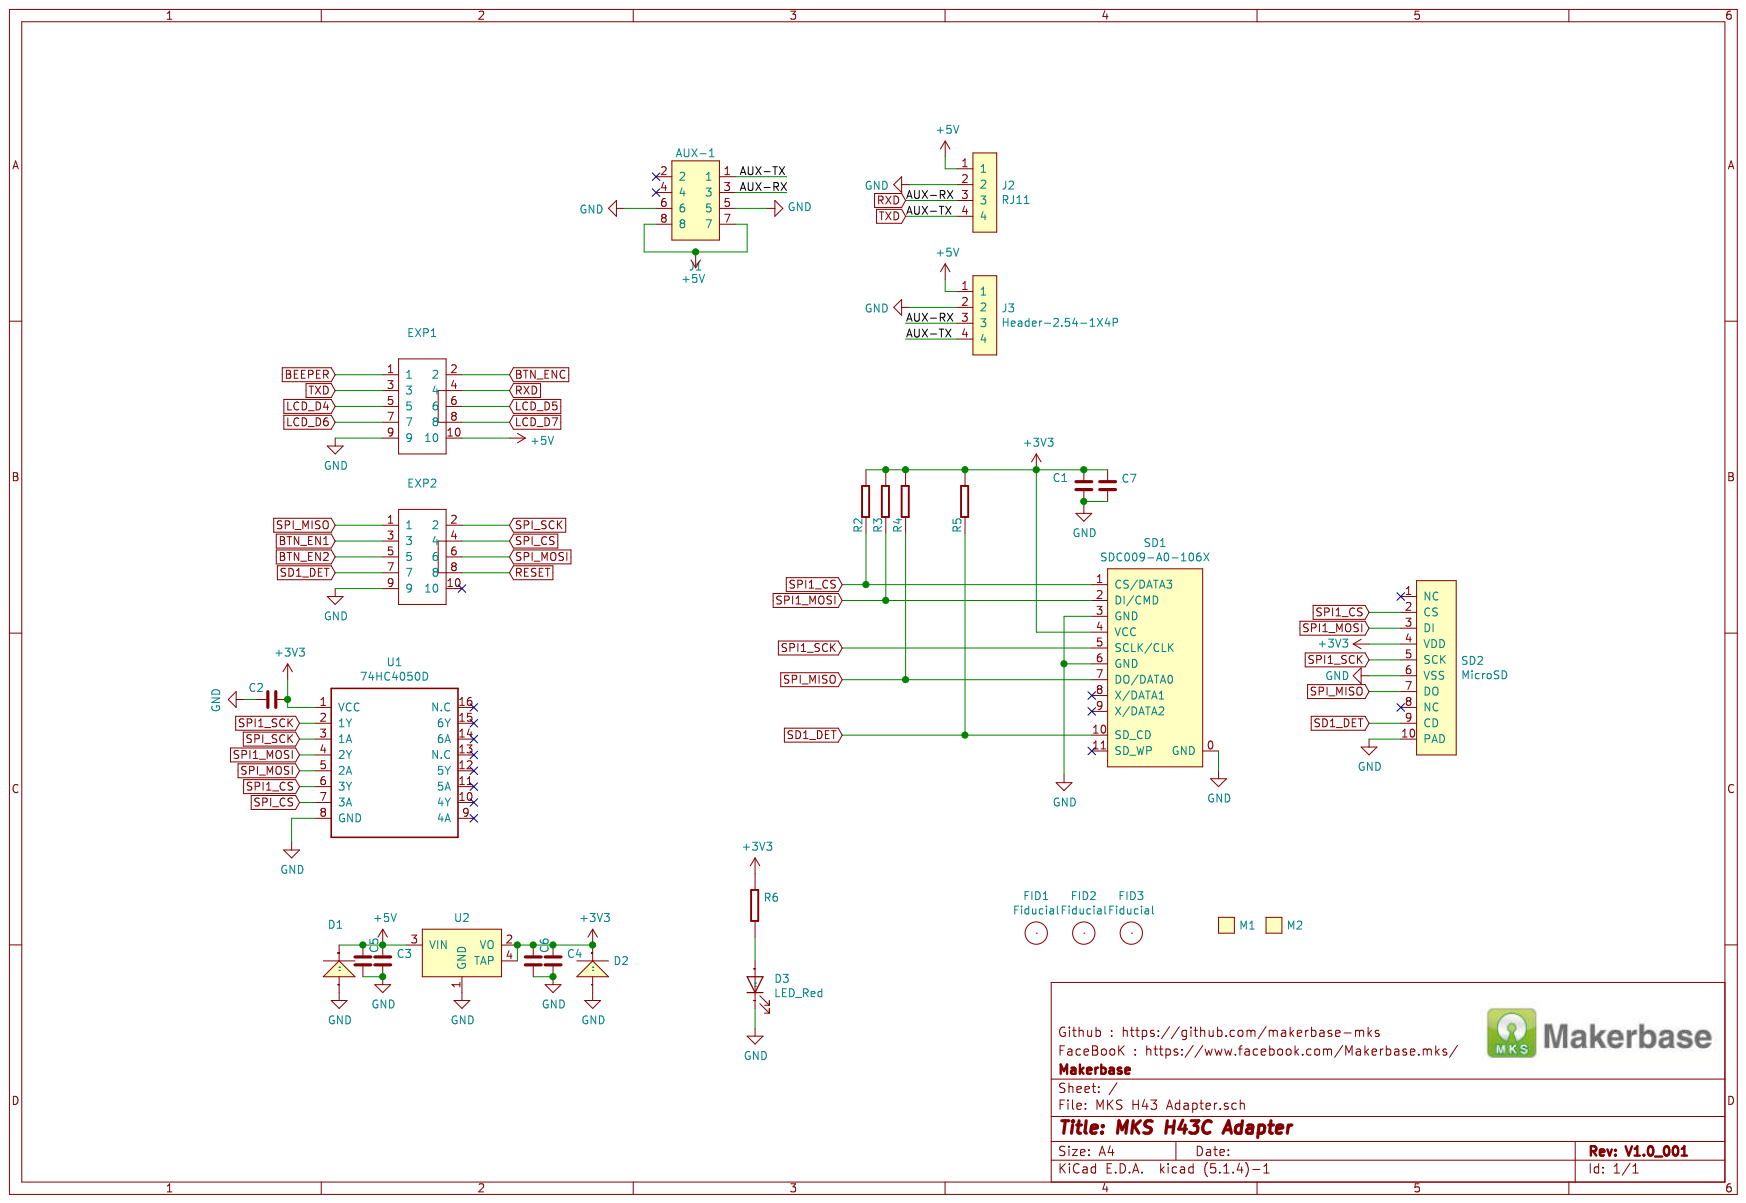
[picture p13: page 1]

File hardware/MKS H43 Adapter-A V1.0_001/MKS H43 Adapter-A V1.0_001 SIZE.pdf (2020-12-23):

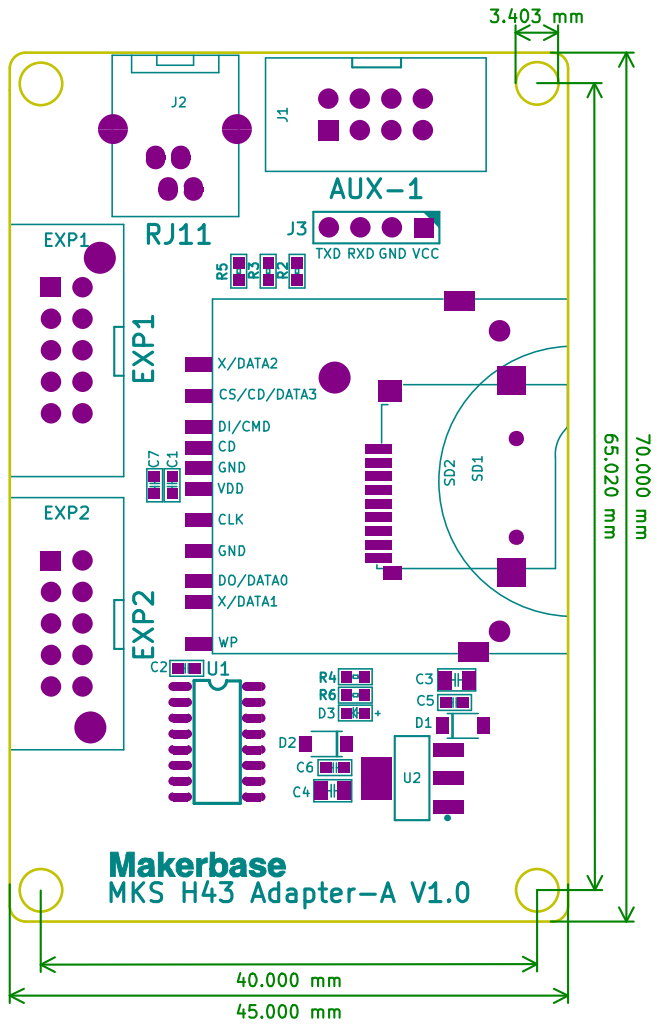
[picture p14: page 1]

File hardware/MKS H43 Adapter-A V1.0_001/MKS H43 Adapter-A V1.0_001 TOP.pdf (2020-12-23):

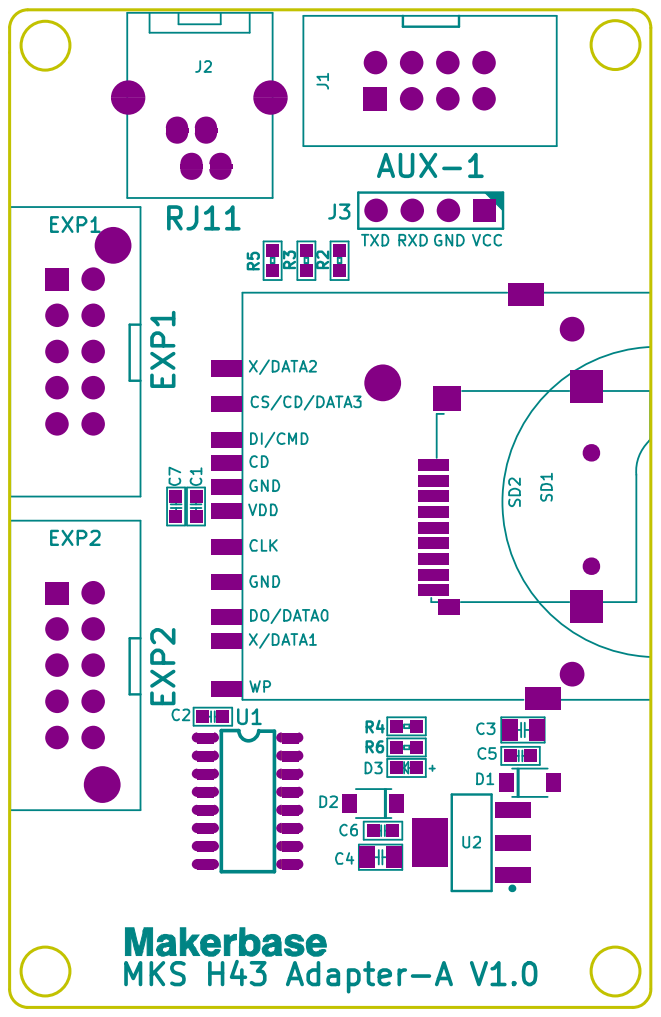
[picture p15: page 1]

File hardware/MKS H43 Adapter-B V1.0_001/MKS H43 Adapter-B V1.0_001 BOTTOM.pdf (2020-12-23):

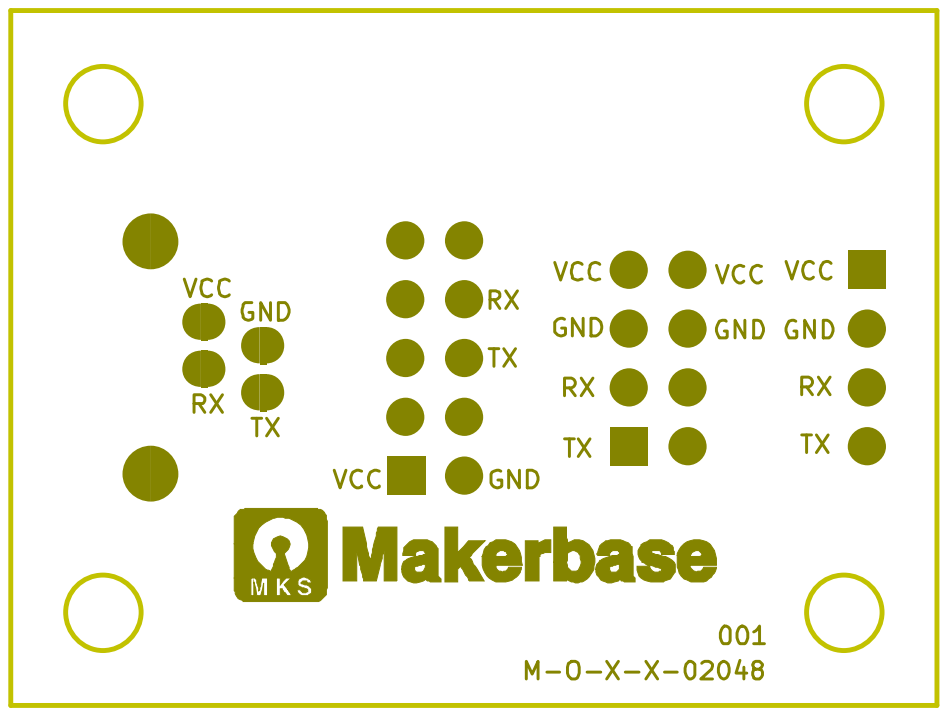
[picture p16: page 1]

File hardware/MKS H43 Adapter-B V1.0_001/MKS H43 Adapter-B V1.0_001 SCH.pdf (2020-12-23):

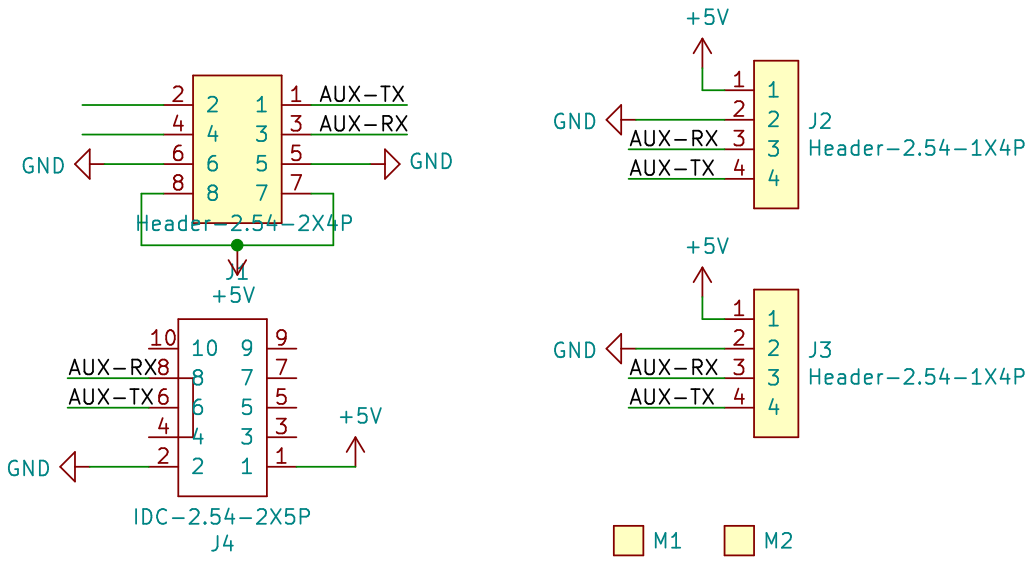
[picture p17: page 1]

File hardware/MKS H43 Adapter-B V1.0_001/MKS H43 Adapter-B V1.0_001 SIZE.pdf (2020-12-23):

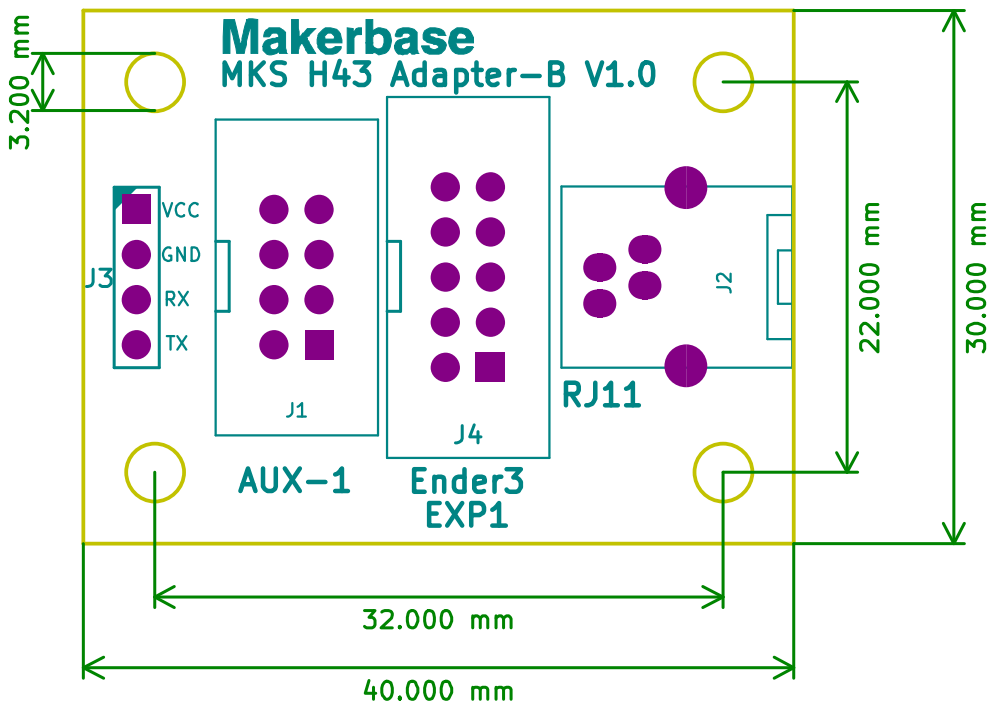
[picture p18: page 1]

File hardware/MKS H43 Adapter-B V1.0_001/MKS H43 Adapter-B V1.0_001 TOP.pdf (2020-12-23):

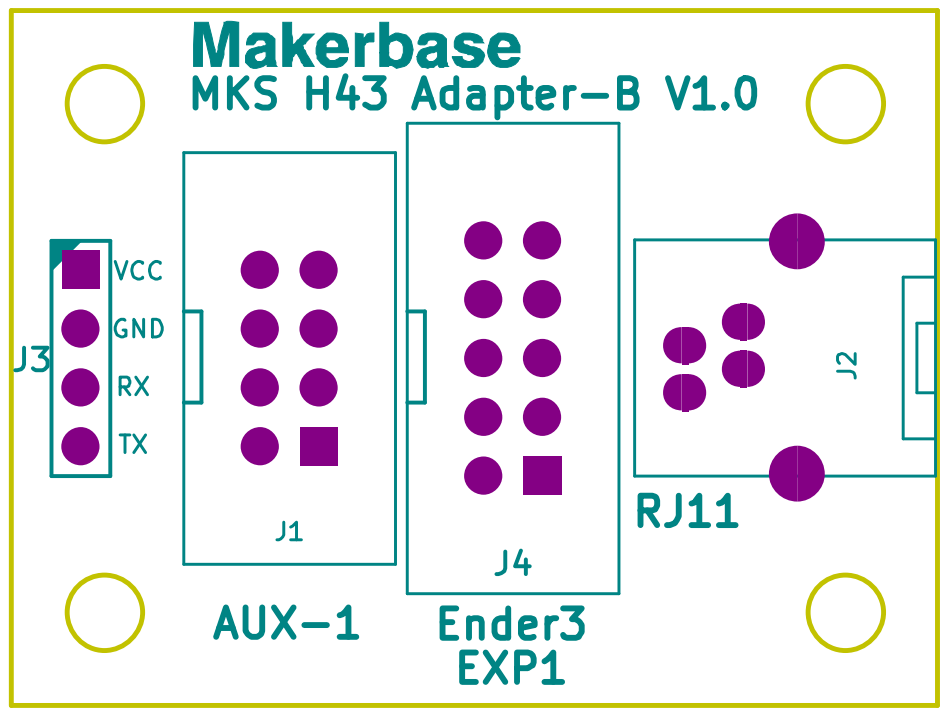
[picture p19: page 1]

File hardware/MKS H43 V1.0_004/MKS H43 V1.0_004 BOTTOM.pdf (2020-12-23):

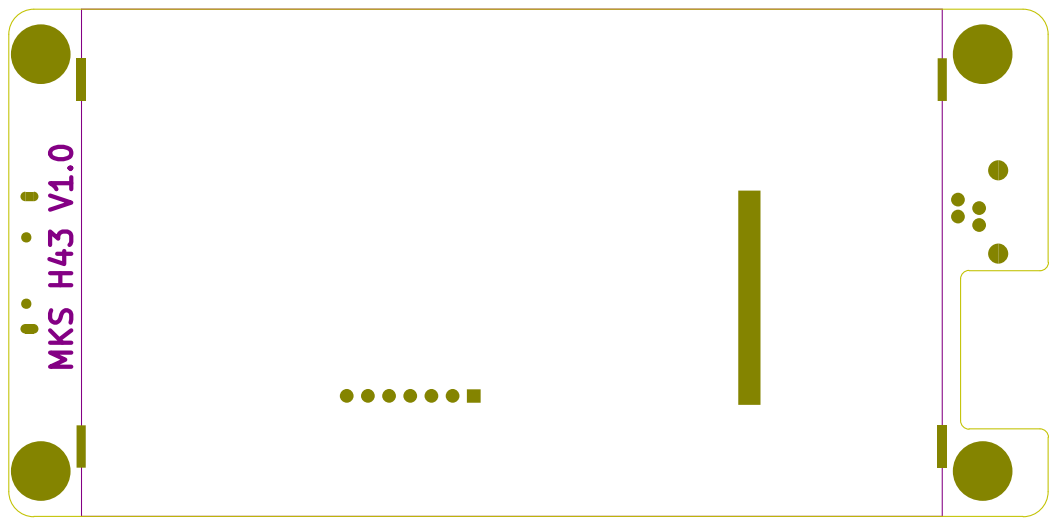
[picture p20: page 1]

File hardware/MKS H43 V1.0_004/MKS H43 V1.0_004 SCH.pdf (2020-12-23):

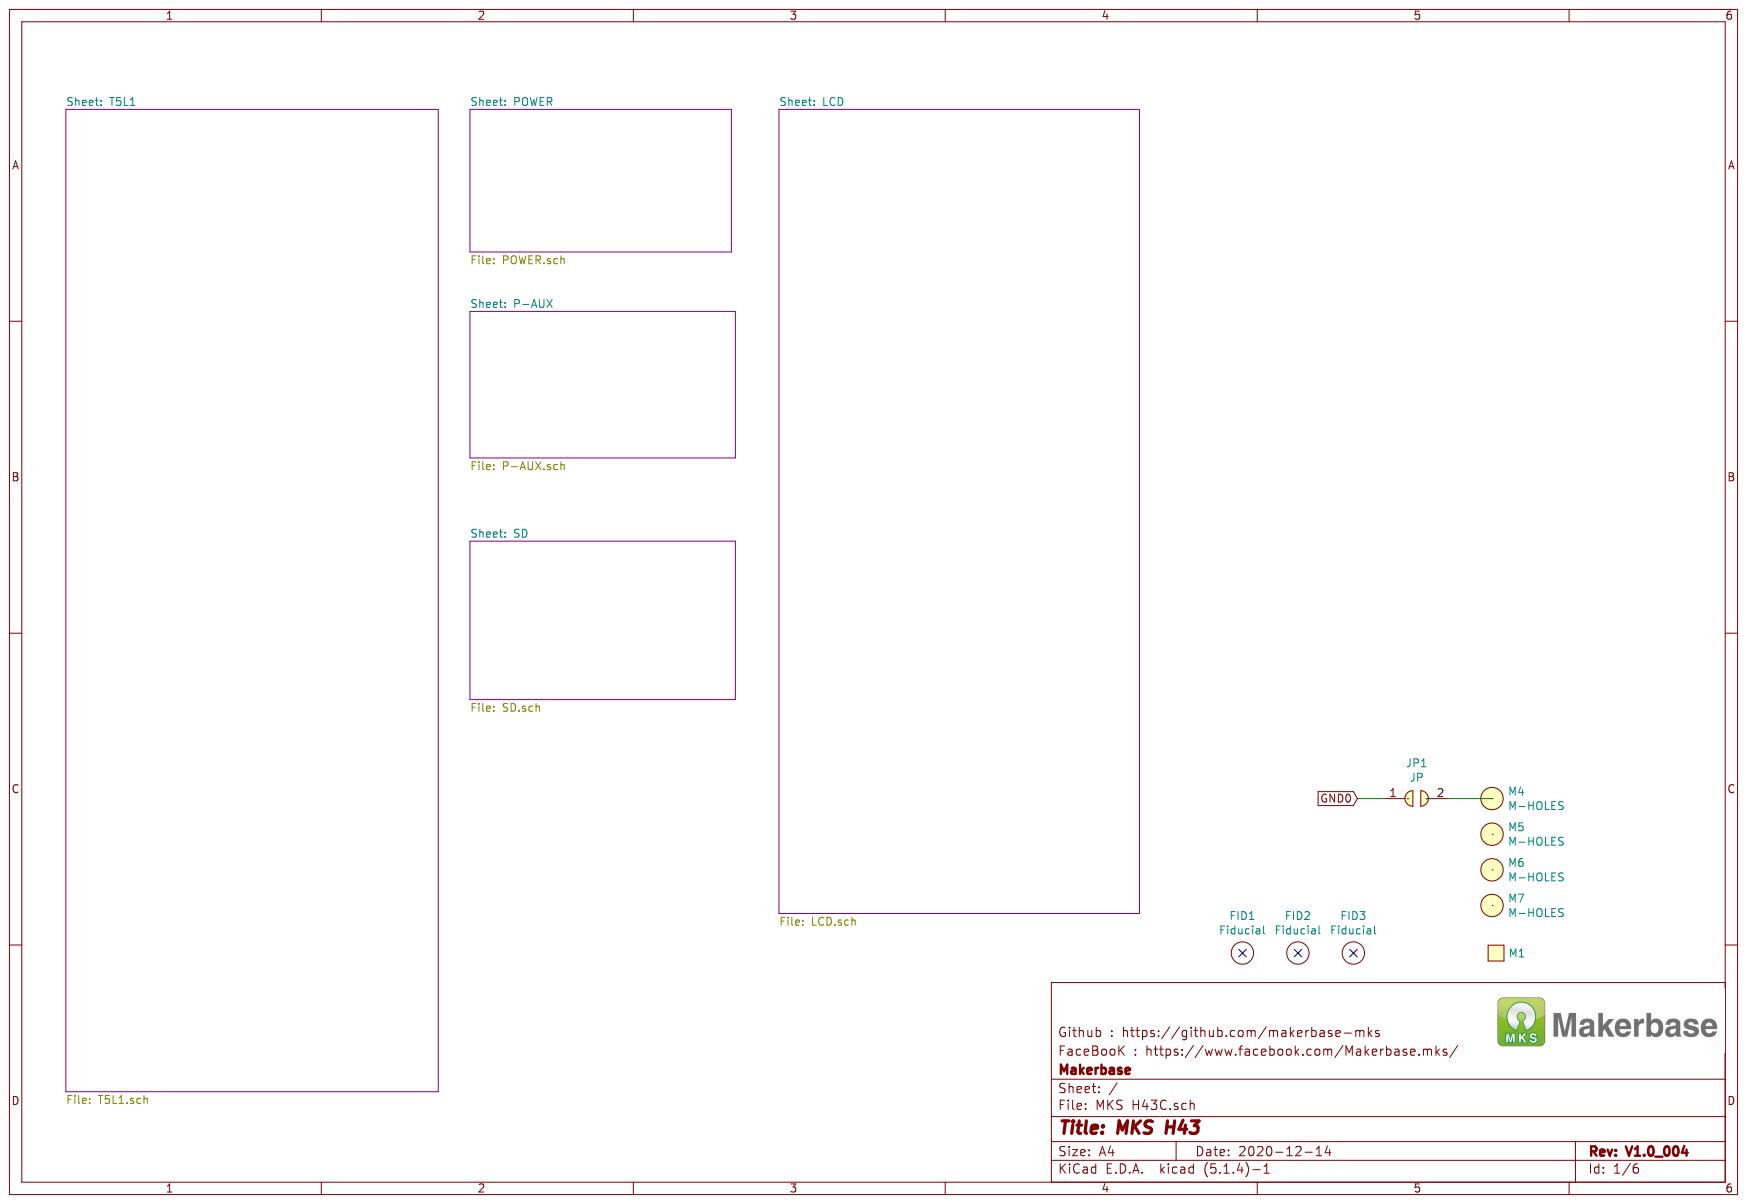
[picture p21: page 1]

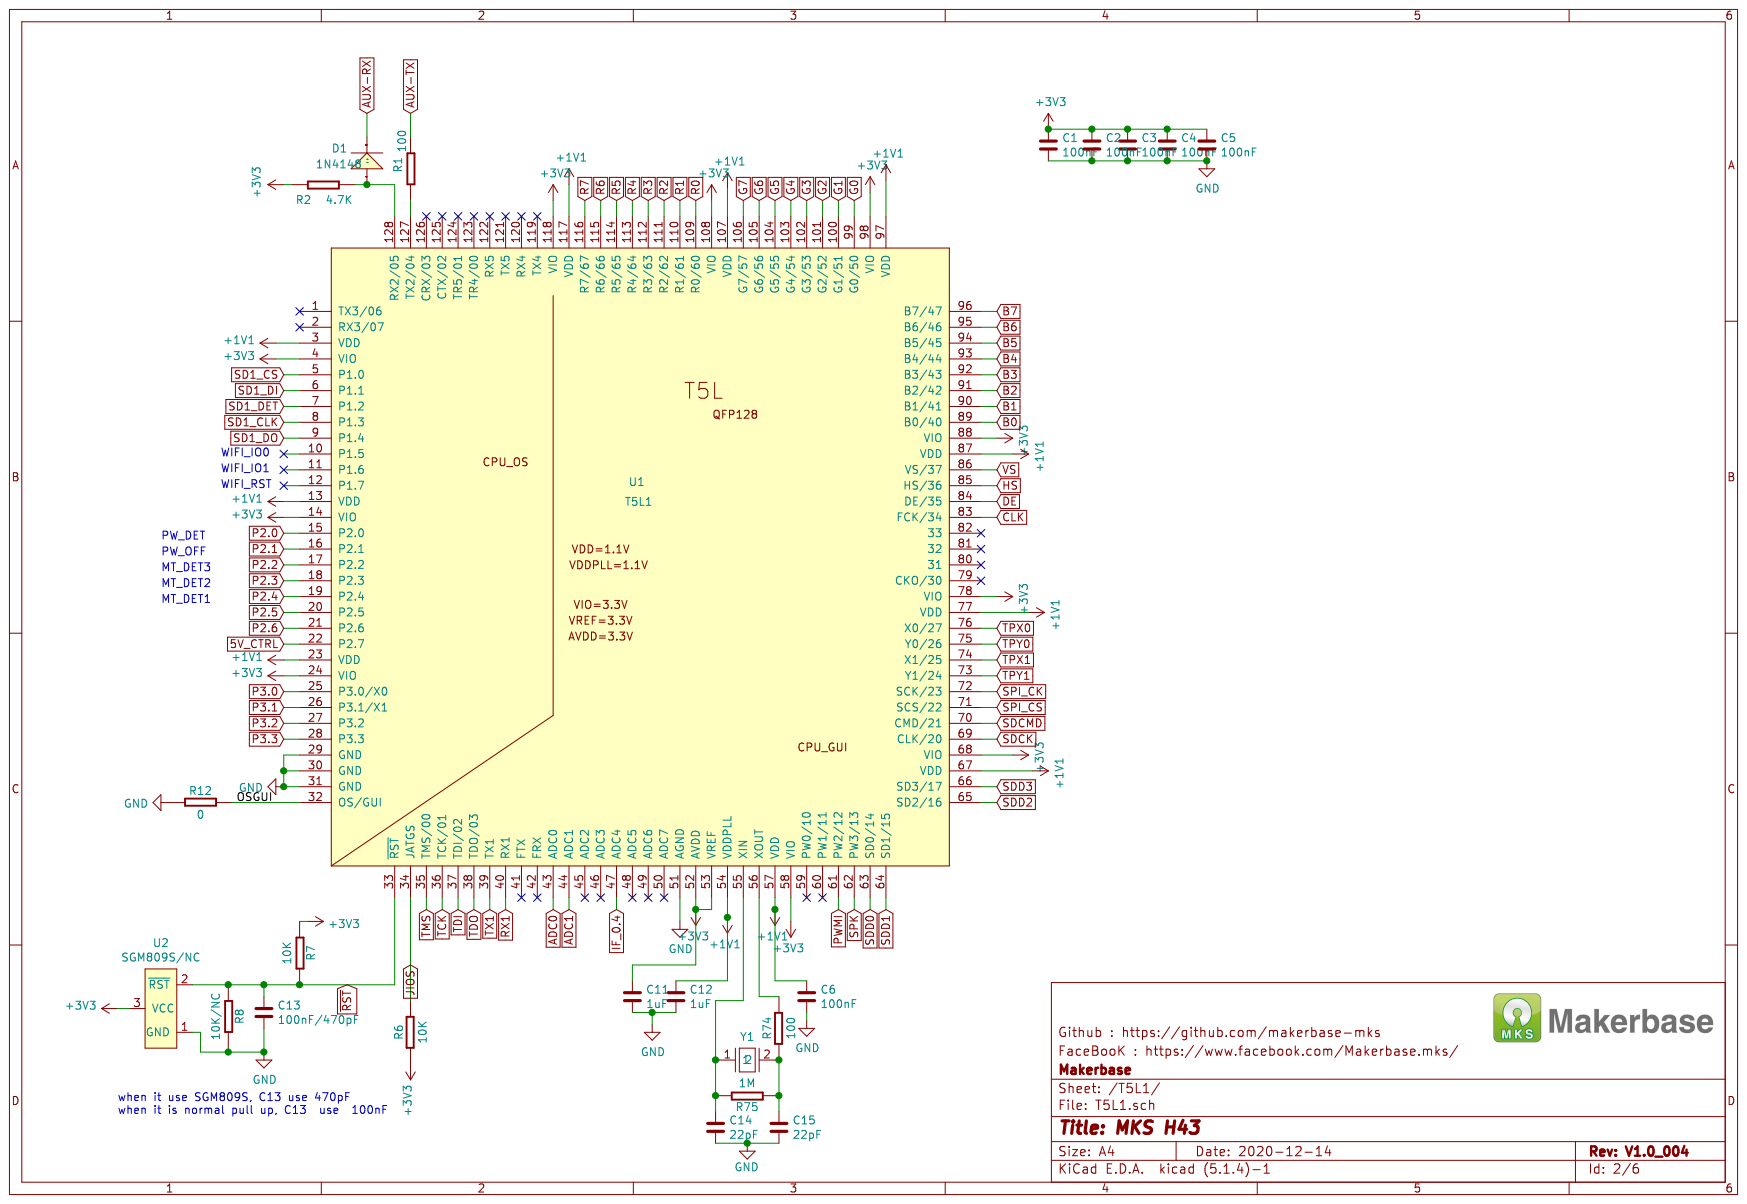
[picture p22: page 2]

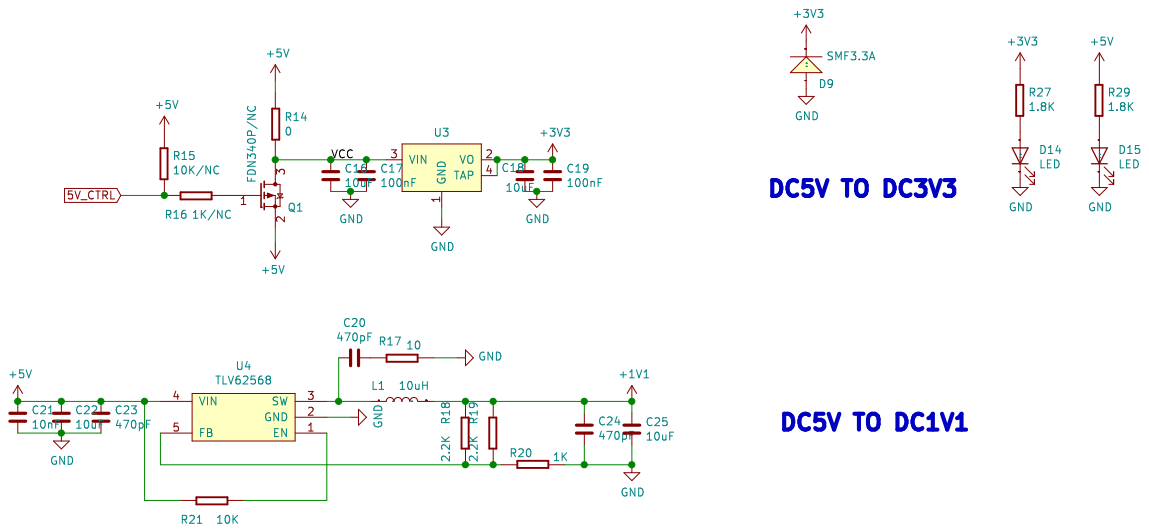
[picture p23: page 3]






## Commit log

2020-12-09 H43 First Commit
    [Configuration.h, Configuration_adv.h, DisplayConfig.xls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]
2020-12-24 add h43 new version
    [Configuration.h, Configuration_adv.h, DisplayConfig.xls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]
2021-01-29 Add the compiled marlin firmware for Creality ender3
2021-02-05 updata V1.31
    [T5LCFG_C1_NoBeep.CFG, T5LCFG_C1_whitBeep.CFG, T5LCFG_with_beep.CFG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]
2021-02-09 add readme
    [T5LCFG_C1_NoBeep.CFG, T5LCFG_C1_whitBeep.CFG, T5LCFG_with_beep.CFG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]
2022-06-22 upload the brackets and shell modules
    [bracket1.STL, bracket2.STL, shell1.STL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]
